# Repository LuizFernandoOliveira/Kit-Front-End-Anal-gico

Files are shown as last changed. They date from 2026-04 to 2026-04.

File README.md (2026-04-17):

# Kit Front-End Analógico




## Descrição
Kit didático completo de Front-End para circuitos analógicos. Este kit é perfeito para se ter na bancada, pois possui diversas funcionalidades úteis durante o desenvolvimente de sistemas microcontrolados e IoT.

<p align="center">
  kitFrontEndAnalogico
</p>

---

## Descrições técnicas

- Possui LDOs de 3V3 e 5V;
- Conectores USB tipo-C e Jack para alimentação do circuito;
- Possui AmpOp Full Diferencial;
- Possui ADC Full Diferencial:
- Possui Filtro ativo de 2ª Oedem Passa-altas, Passa-baixas, Passa-faixas, Rejeita-faixas;
- Possui Filtros passivos;
- Possui Buffer;
- Possui AmpOp de instrumentação;
- Possui divisores de tensão;
- Possui resistores de Pull-Up e/ou Pull-Down;
- Possui AmpOp RRIO, Ultra-Low Power, Ultra-Low Noise Não Inversor, Inversor, Integrador, Diferenciador;
- Possui chaves analogicas;
- Possui chaves digitais;
- Possui botões e LEDS;
- Possui sensores analógicos;
- Possui diodos Schotky;
- Possui diversas tensões de referência;
- Possui diversos charge pumps.

---

## Estrutura do repositório
Os arquivos de hardware foram desenvolvidos utilizando o KiCad 9.0.
- **`.kicad_pcb`**: Layout da placa de circuito impresso (Board).
- **`.kicad_sch`**: Esquemático eletrônico do sistema (Schematic).
- **`.kicad_pro`**: Gerenciador de projeto do KiCad (Project).

---

## Autor
**Dr. Luiz Fernando Pinto de Oliveira**

*Engenheiro Eletrônico especializado em Sistemas Embarcados e Ultra-Low Power.*
- **Website:** [FAPLO](https://faplo.webnode.page/)
- **LinkedIn:** [lfpo](https://www.linkedin.com/in/lfpo/)

---

Shield: [][cc-by-nc-nd]

This work is licensed under a
[Creative Commons Attribution-NonCommercial-NoDerivs 4.0 International License][cc-by-nc-nd].

[][cc-by-nc-nd]

[cc-by-nc-nd]: http://creativecommons.org/licenses/by-nc-nd/4.0/
[cc-by-nc-nd-image]: https://licensebuttons.net/l/by-nc-nd/4.0/88x31.png
[cc-by-nc-nd-shield]: https://img.shields.io/badge/License-CC%20BY--NC--ND%204.0-lightgrey.svg

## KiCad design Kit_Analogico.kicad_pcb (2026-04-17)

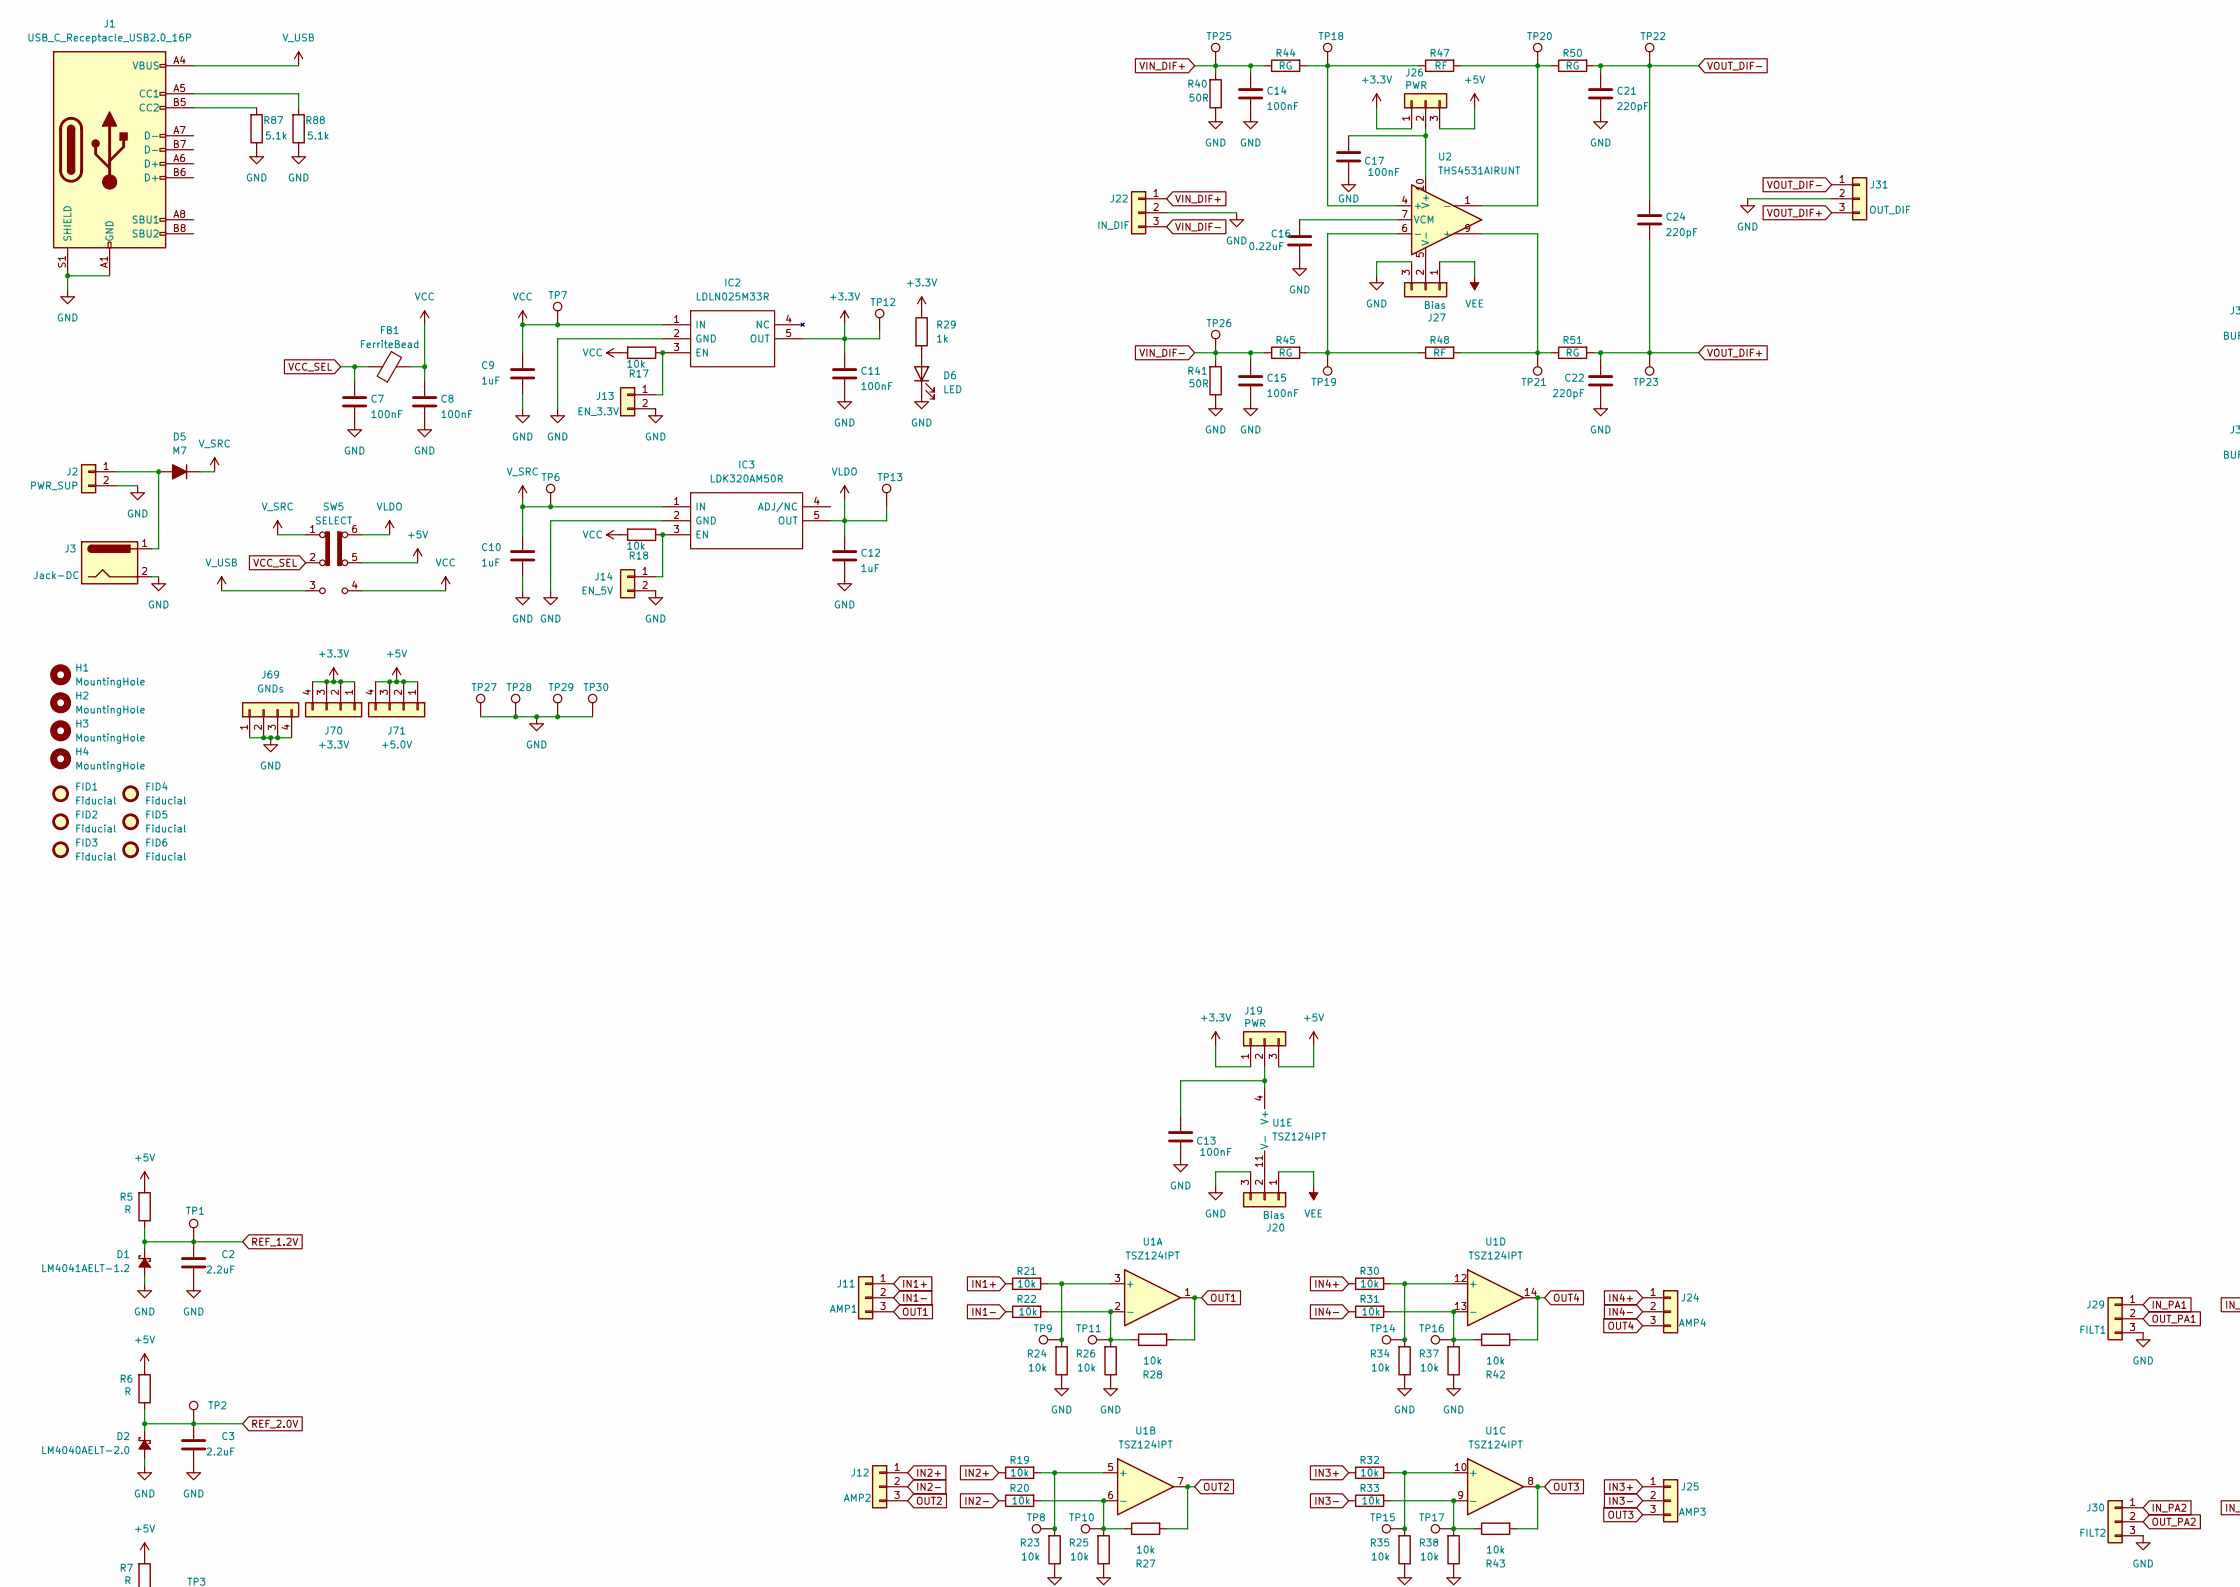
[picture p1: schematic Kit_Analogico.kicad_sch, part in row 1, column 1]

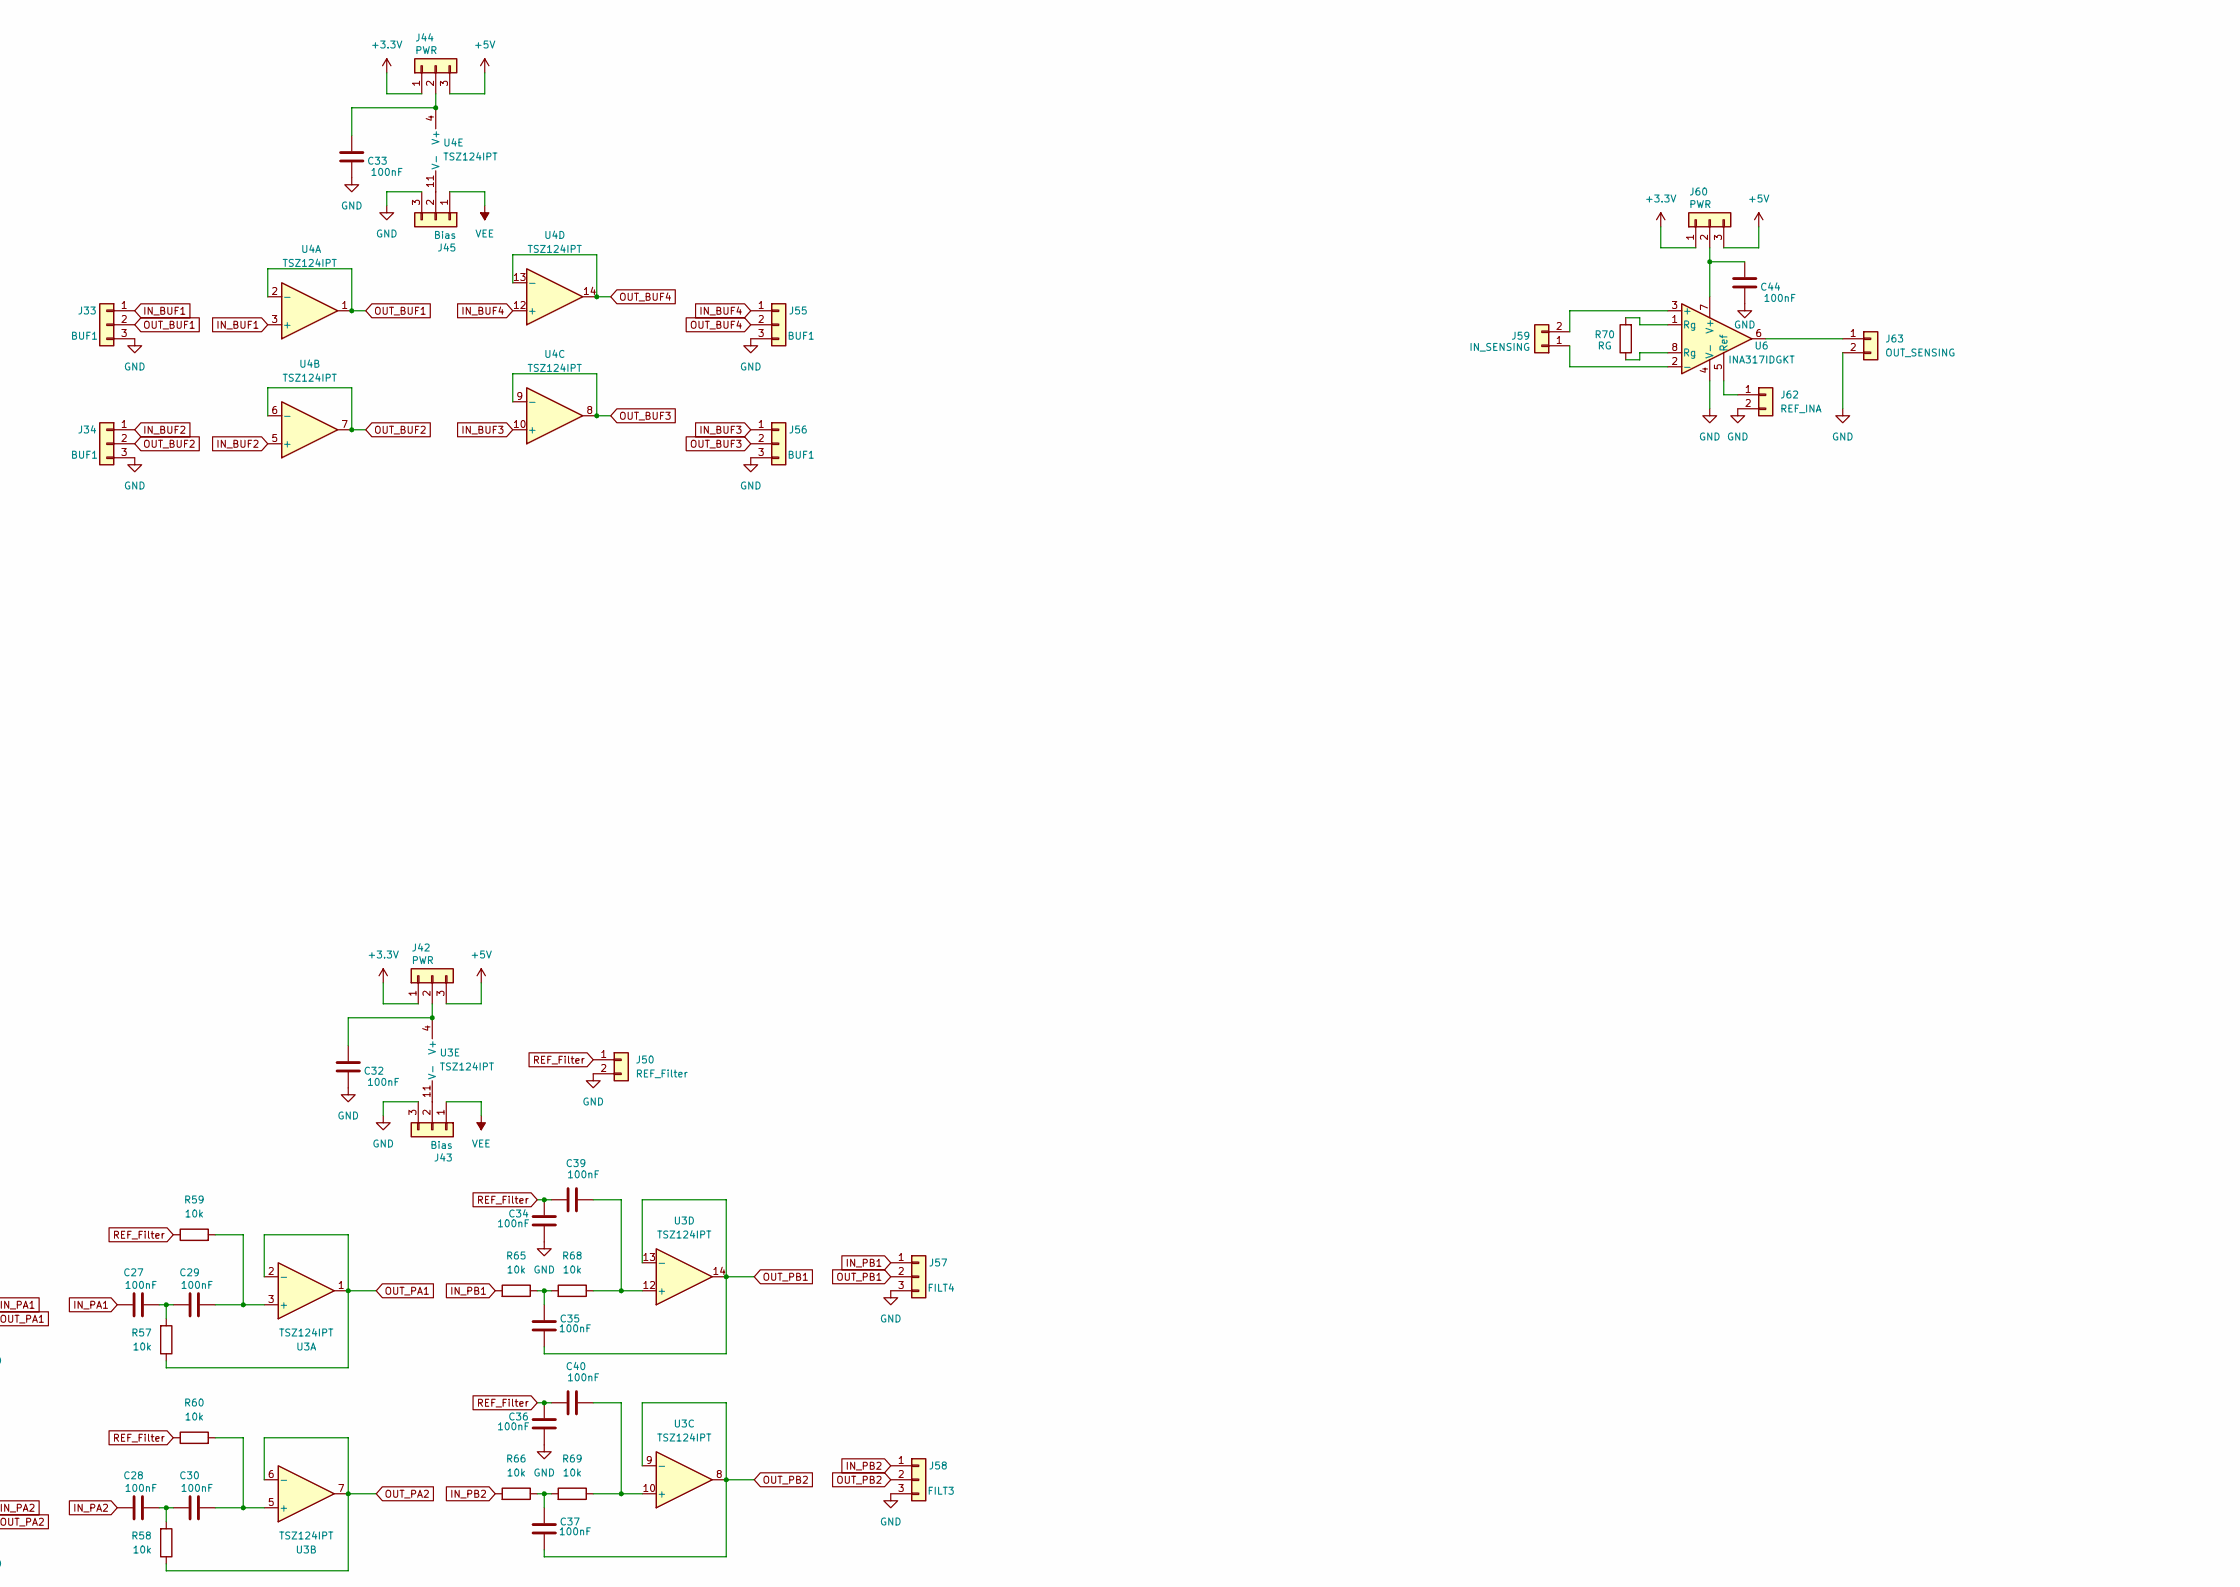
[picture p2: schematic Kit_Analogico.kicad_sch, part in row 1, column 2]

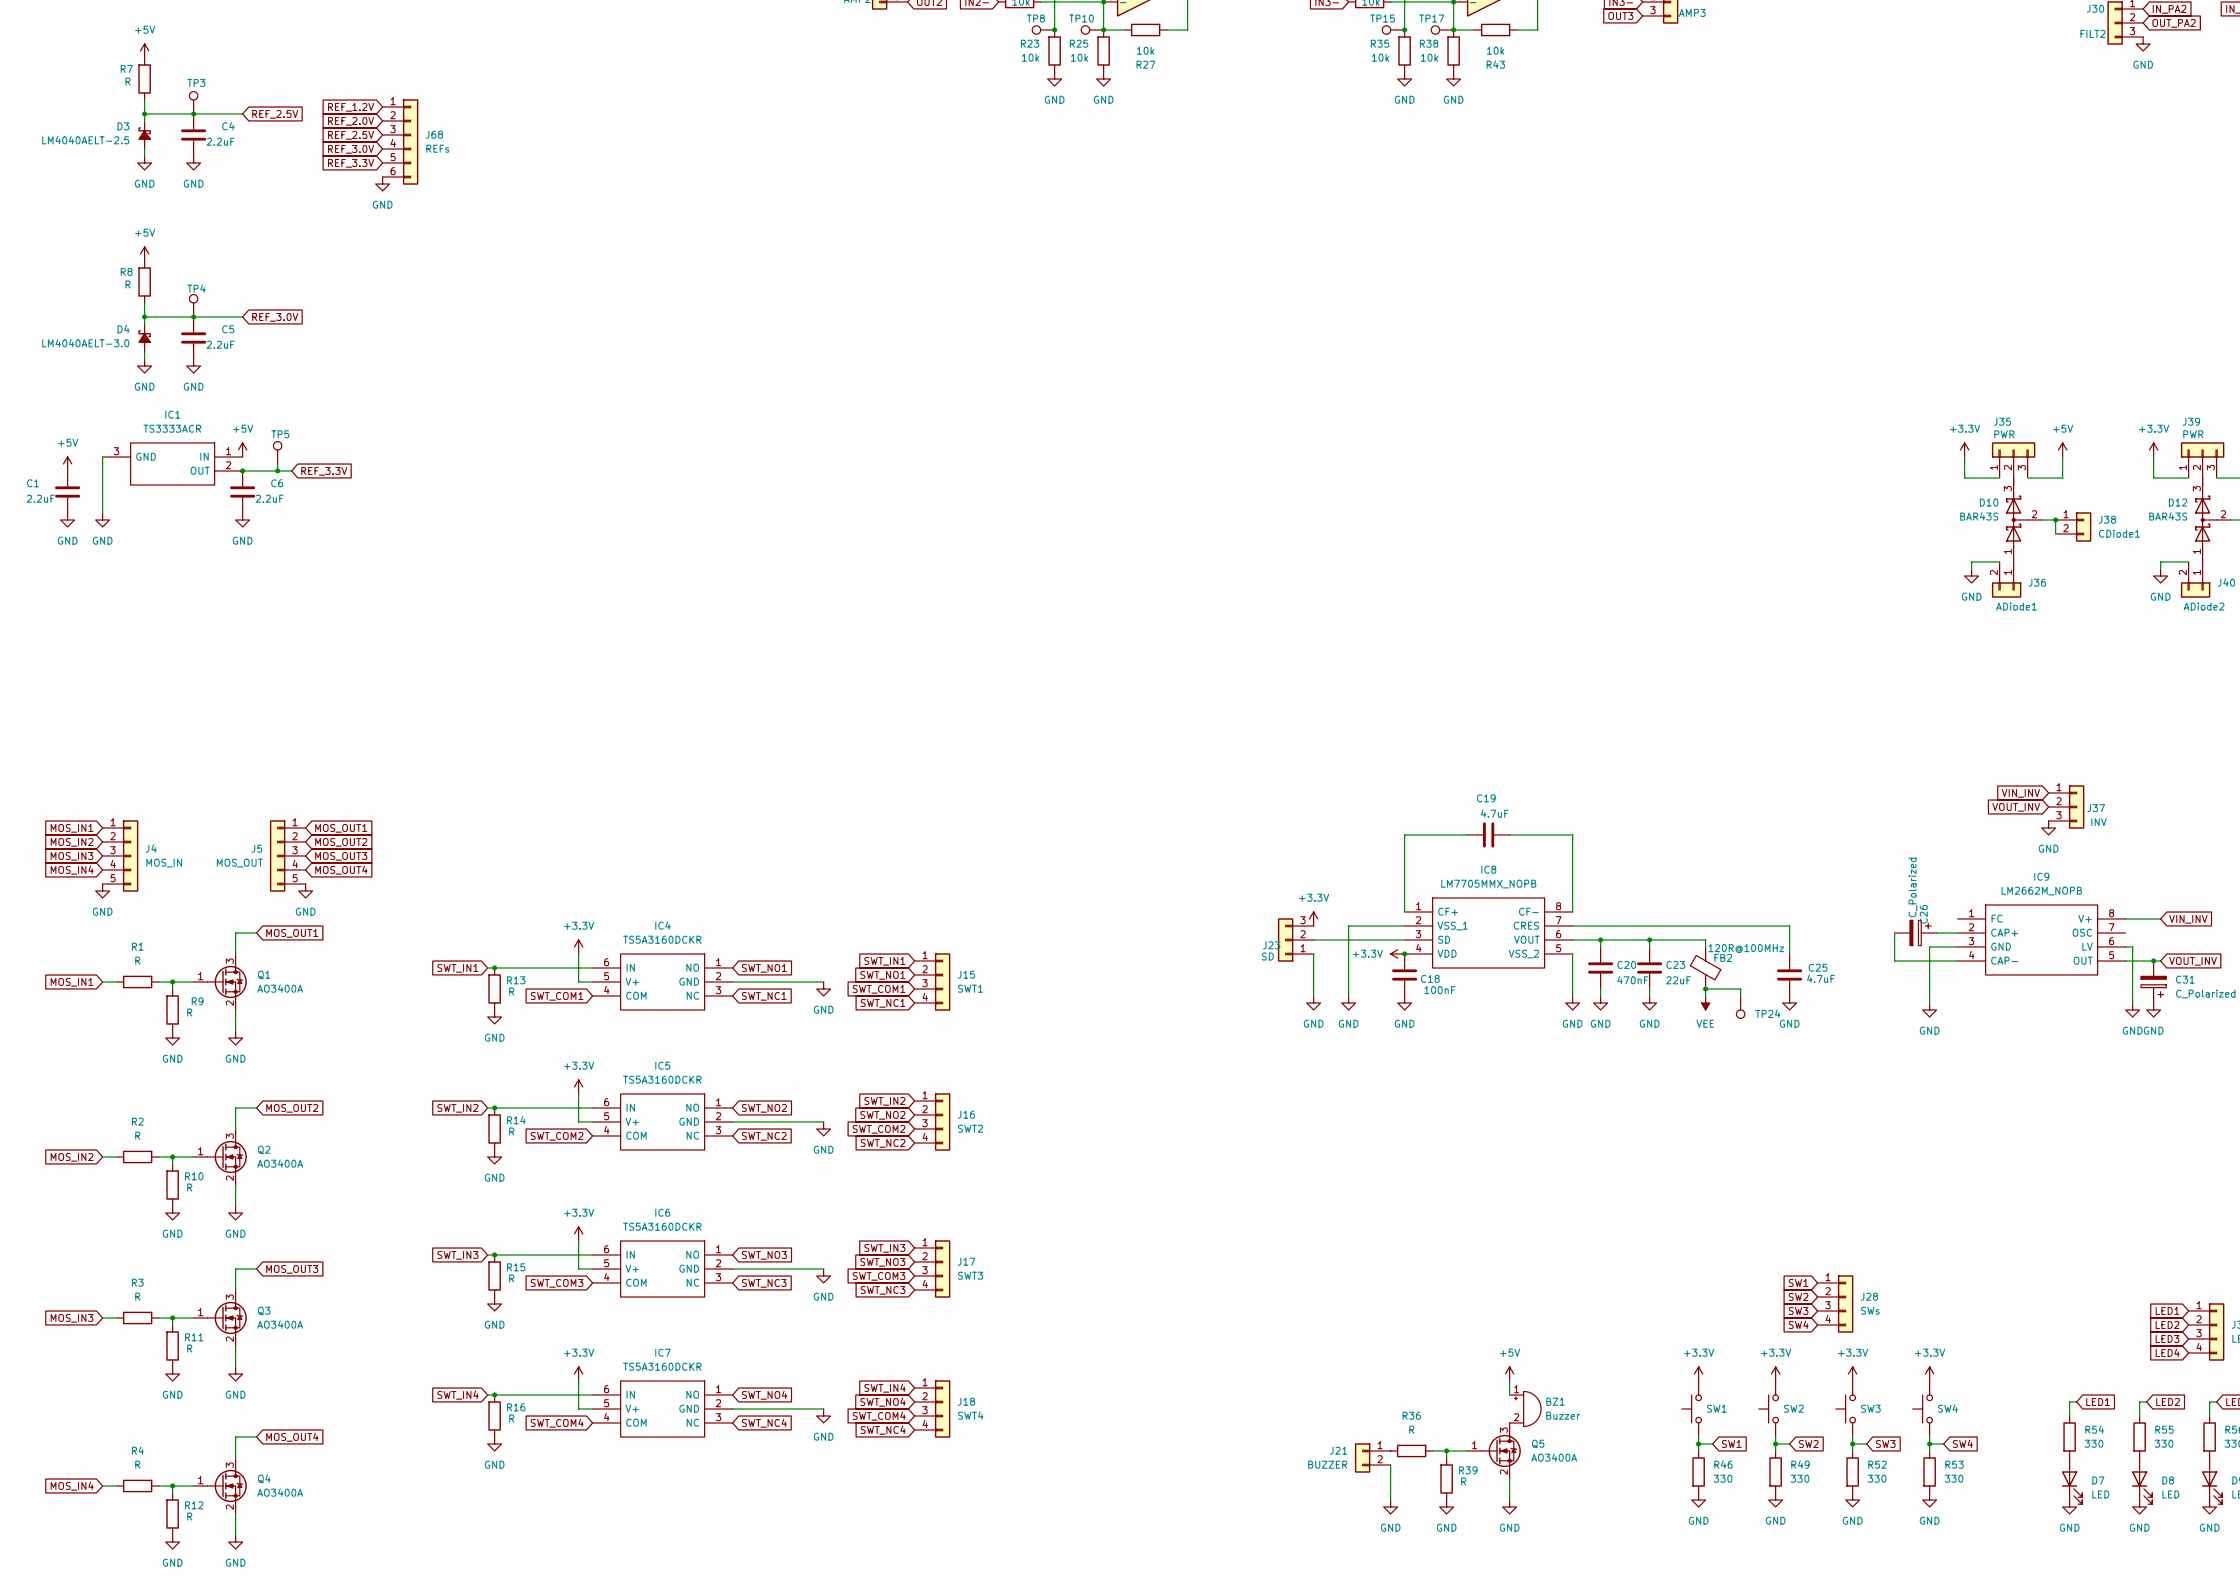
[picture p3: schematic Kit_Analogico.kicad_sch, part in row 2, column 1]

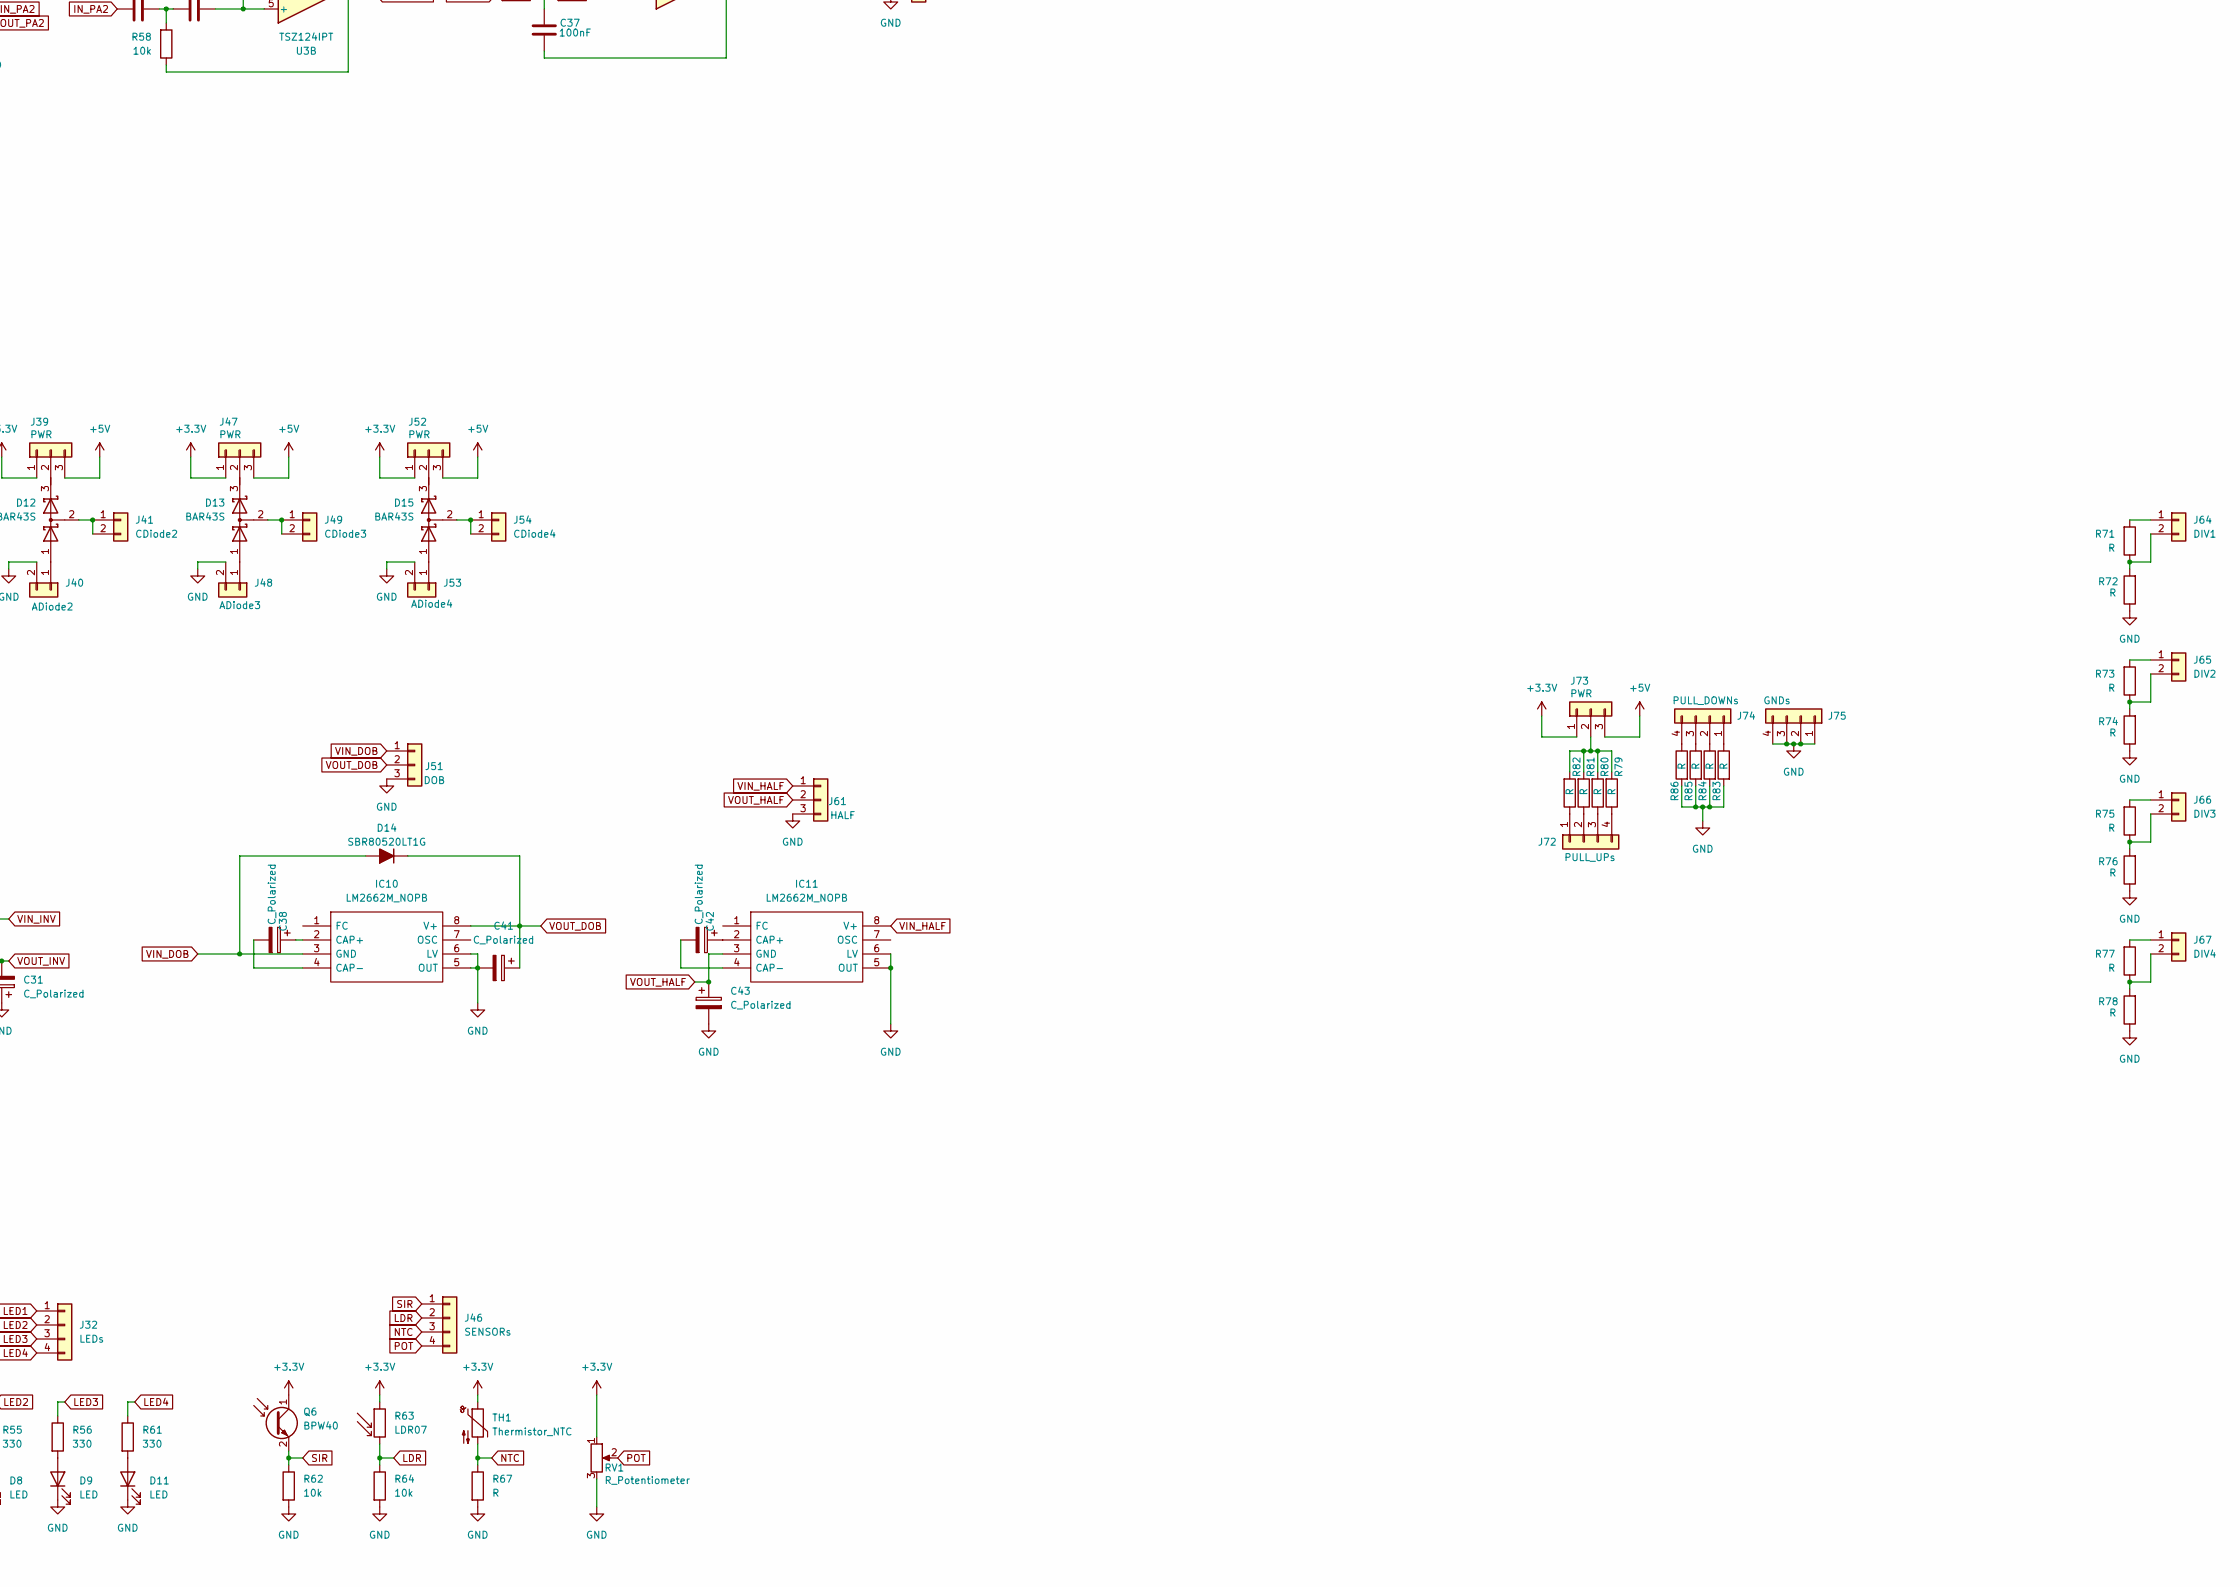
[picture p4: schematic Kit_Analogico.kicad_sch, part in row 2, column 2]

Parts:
BZ1: Buzzer; Buzzer_12x9.5RM7.6
C1, C2, C3, C4, C5, C6: 2.2uF; C_0805_2012Metric
C7, C8, C11, C13, C14, C15, C17, C18, C27, C28, C29, C30, C32, C33, C34, C35, C36, C37, C39, C40, C44: 100nF; C_0805_2012Metric
C9, C10, C12: 1uF; C_0805_2012Metric
C16: 0.22uF; C_0805_2012Metric
C19, C25: 4.7uF; C_0805_2012Metric
C20: 470nF; C_0805_2012Metric
C21, C22, C24: 220pF; C_0805_2012Metric
C23: 22uF; C_0805_2012Metric
C26, C31, C38, C41, C42, C43: C_Polarized; CP_EIA-3216-10_Kemet-I_Pad1.58x1.35mm_HandSolder
D1: LM4041AELT-1.2; LM4040AELT25
D2: LM4040AELT-2.0; LM4040AELT25
D3: LM4040AELT-2.5; LM4040AELT25
D4: LM4040AELT-3.0; LM4040AELT25
D5: M7; D_SMA
D6, D7, D8, D9, D11: LED; LED_0805_2012Metric
D10, D12, D13, D15: BAR43S; SOT95P237X112-3N
D14: SBR80520LT1G; SOD3716X135N
FB1: FerriteBead; L_0805_2012Metric
FB2: 120R@100MHz; L_0805_2012Metric
FID1, FID2, FID3, FID4, FID5, FID6: Fiducial; Fiducial_1mm_Mask2mm
H1, H2, H3, H4: MountingHole; MountingHole_3.2mm_M3_DIN965
IC1: TS3333ACR; LM4040CELT20; Manufacturer_Part_Number TS3333ACR
IC2: LDLN025M33R; SOT95P280X145-5N; Manufacturer_Part_Number LDLN025M33R; Mouser Part Number 511-LDLN025M33R
IC3: LDK320AM50R; SOT95P280X145-5N; Manufacturer_Part_Number LDK320AM50R; Mouser Part Number 511-LDK320AM50R
IC4, IC5, IC6, IC7: TS5A3160DCKR; SOT65P210X110-6N; Manufacturer_Part_Number TS5A3160DCKR; Mouser Part Number 595-TS5A3160DCKR
IC8: LM7705MMX_NOPB; SOP65P490X110-8N; Manufacturer_Part_Number LM7705MMX/NOPB; Mouser Part Number 926-LM7705MMX/NOPB
IC9, IC10, IC11: LM2662M_NOPB; SOIC127P600X175-8N; Manufacturer_Part_Number LM2662M/NOPB; Mouser Part Number 926-LM2662M/NOPB
J1: USB_C_Receptacle_USB2.0_16P; USB_C_Receptacle_HRO_TYPE-C-31-M-12
J2: PWR_SUP; TerminalBlock_Altech_AK300-2_P5.00mm
J3: Jack-DC; BarrelJack_Horizontal
J4: MOS_IN; PinHeader_1x05_P2.54mm_Vertical
J5: MOS_OUT; PinHeader_1x05_P2.54mm_Vertical
J11: AMP1; PinHeader_1x03_P2.54mm_Vertical
J12: AMP2; PinHeader_1x03_P2.54mm_Vertical
J13: EN_3.3V; PinHeader_1x02_P2.54mm_Vertical
J14: EN_5V; PinHeader_1x02_P2.54mm_Vertical
J15: SWT1; PinHeader_1x04_P2.54mm_Vertical
J16: SWT2; PinHeader_1x04_P2.54mm_Vertical
J17: SWT3; PinHeader_1x04_P2.54mm_Vertical
J18: SWT4; PinHeader_1x04_P2.54mm_Vertical
J19, J26, J35, J39, J42, J44, J47, J52, J60, J73: PWR; PinHeader_1x03_P2.54mm_Vertical
J20, J27, J43, J45: Bias; PinHeader_1x03_P2.54mm_Vertical
J21: BUZZER; PinHeader_1x02_P2.54mm_Vertical
J22: IN_DIF; PinHeader_1x03_P2.54mm_Vertical
J23: SD; PinHeader_1x03_P2.54mm_Vertical
J24: AMP4; PinHeader_1x03_P2.54mm_Vertical
J25: AMP3; PinHeader_1x03_P2.54mm_Vertical
J28: SWs; PinHeader_1x04_P2.54mm_Vertical
J29: FILT1; PinHeader_1x03_P2.54mm_Vertical
J30: FILT2; PinHeader_1x03_P2.54mm_Vertical
J31: OUT_DIF; PinHeader_1x03_P2.54mm_Vertical
J32: LEDs; PinHeader_1x04_P2.54mm_Vertical
J33, J34, J55, J56: BUF1; PinHeader_1x03_P2.54mm_Vertical
J36: ADiode1; PinHeader_1x02_P2.54mm_Vertical
J37: INV; PinHeader_1x03_P2.54mm_Vertical
J38: CDiode1; PinHeader_1x02_P2.54mm_Vertical
J40: ADiode2; PinHeader_1x02_P2.54mm_Vertical
J41: CDiode2; PinHeader_1x02_P2.54mm_Vertical
J46: SENSORs; PinHeader_1x04_P2.54mm_Vertical
J48: ADiode3; PinHeader_1x02_P2.54mm_Vertical
J49: CDiode3; PinHeader_1x02_P2.54mm_Vertical
J50: REF_Filter; PinHeader_1x02_P2.54mm_Vertical
J51: DOB; PinHeader_1x03_P2.54mm_Vertical
J53: ADiode4; PinHeader_1x02_P2.54mm_Vertical
J54: CDiode4; PinHeader_1x02_P2.54mm_Vertical
J57: FILT4; PinHeader_1x03_P2.54mm_Vertical
J58: FILT3; PinHeader_1x03_P2.54mm_Vertical
J59: IN_SENSING; PinHeader_1x02_P2.54mm_Vertical
J61: HALF; PinHeader_1x03_P2.54mm_Vertical
J62: REF_INA; PinHeader_1x02_P2.54mm_Vertical
J63: OUT_SENSING; PinHeader_1x02_P2.54mm_Vertical
J64: DIV1; PinHeader_1x02_P2.54mm_Vertical
J65: DIV2; PinHeader_1x02_P2.54mm_Vertical
J66: DIV3; PinHeader_1x02_P2.54mm_Vertical
J67: DIV4; PinHeader_1x02_P2.54mm_Vertical
J68: REFs; PinHeader_1x06_P2.54mm_Vertical
J69, J75: GNDs; PinHeader_1x04_P2.54mm_Vertical
J70: +3.3V; PinHeader_1x04_P2.54mm_Vertical
J71: +5.0V; PinHeader_1x04_P2.54mm_Vertical
J72: PULL_UPs; PinHeader_1x04_P2.54mm_Vertical
J74: PULL_DOWNs; PinHeader_1x04_P2.54mm_Vertical
Q1, Q2, Q3, Q4, Q5: AO3400A; SOT-23
Q6: BPW40; LED_D5.0mm_Clear
R1, R2, R3, R4, R5, R6, R7, R8, R9, R10, R11, R12, R13, R14, R15, R16, R36, R39, R67, R71, R72, R73, R74, R75, R76, R77, R78, R79, R80, R81, R82, R83, R84, R85, R86: R; R_0805_2012Metric
R17, R18, R19, R20, R21, R22, R23, R24, R25, R26, R27, R28, R30, R31, R32, R33, R34, R35, R37, R38, R42, R43, R57, R58, R59, R60, R62, R64, R65, R66, R68, R69: 10k; R_0805_2012Metric
R29: 1k; R_0805_2012Metric
R40, R41: 50R; R_0805_2012Metric
R44, R45, R50, R51, R70: RG; R_0805_2012Metric
R46, R49, R52, R53, R54, R55, R56, R61: 330; R_0805_2012Metric
R47, R48: RF; R_0805_2012Metric
R63: LDR07; R_LDR_5.1x4.3mm_P3.4mm_Vertical
R87, R88: 5.1k; R_0805_2012Metric
RV1: R_Potentiometer; RM065503
SW1, SW2, SW3, SW4: SW_Push; SW_PUSH_6mm_H5mm
SW5: SELECT; SW_E-Switch_EG1271_SPDT
TH1: Thermistor_NTC; PinHeader_1x02_P2.54mm_Vertical
TP1, TP2, TP3, TP4, TP5, TP6, TP7, TP8, TP9, TP10, TP11, TP12, TP13, TP14, TP15, TP16, TP17, TP18, TP19, TP20, TP21, TP22, TP23, TP24, TP25, TP26, TP27, TP28, TP29, TP30: TestPoint; TestPoint_Loop_D1.80mm_Drill1.0mm_Beaded
U1, U3, U4: TSZ124IPT; SOP65P640X120-14N
U2: THS4531AIRUNT; QFN50P200X200X80-10N-D
U6: INA317IDGKT; SOP65P490X110-8N

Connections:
+3.3V: C11.1, C18.2, IC2.5 (OUT), IC4.5 (V+), IC5.5 (V+), IC6.5 (V+), IC7.5 (V+), IC8.4 (VDD), J19.1, J23.3, J26.1, J35.1, J39.1, J42.1, J44.1, J47.1, J52.1, J60.1, J70.1, J70.2, J70.3, J70.4, J73.1, Q6.1 (C), R29.1, R63.1, RV1.1, SW1.2, SW2.2, SW3.2, SW4.2, TH1.1, TP12.1
+5V: BZ1.1 (+), C1.1, IC1.1 (IN), J19.3, J26.3, J35.3, J39.3, J42.3, J44.3, J47.3, J52.3, J60.3, J71.1, J71.2, J71.3, J71.4, J73.3, R5.2, R6.2, R7.2, R8.2, SW5.5 (B)
GND: C1.2, C2.2, C3.2, C4.2, C5.2, C6.2, C7.2, C8.2, C9.2, C10.2, C11.2, C12.2, C13.1, C14.2, C15.2, C16.2, C17.1, C18.1, C20.2, C21.2, C22.2, C23.2, C25.1, C31.1, C32.1, C33.1, C34.1, C36.1, C41.2, C43.2, C44.1, D1.2 (A), D2.2 (A), D3.2 (A), D4.2 (A), D6.1 (K), D7.1 (K), D8.1 (K), D9.1 (K), D11.1 (K), IC1.3 (GND), IC2.2 (GND), IC3.2 (GND), IC4.2 (GND), IC5.2 (GND), IC6.2 (GND), IC7.2 (GND), IC8.2 (VSS_1), IC8.5 (VSS_2), IC9.3 (GND), IC9.6 (LV), IC10.5 (OUT), IC10.6 (LV), IC11.5 (OUT), IC11.6 (LV), J1.A1 (GND), J1.A12 (GND), J1.B1 (GND), J1.B12 (GND), J1.S1 (SHIELD), J2.2, J3.2, J4.5, J5.5, J13.2, J14.2, J20.3, J21.2, J22.2, J23.1, J27.3, J29.3, J30.3, J31.2, J33.3, J34.3, J36.2, J37.3, J40.2, J43.3, J45.3, J48.2, J50.2, J51.3, J53.2, J55.3, J56.3, J57.3, J58.3, J61.3, J62.2, J63.2, J68.6, J69.1, J69.2, J69.3, J69.4, J75.1, J75.2, J75.3, J75.4, Q1.2 (S), Q2.2 (S), Q3.2 (S), Q4.2 (S), Q5.2 (S), R9.1, R10.1, R11.1, R12.1, R13.1, R14.1, R15.1, R16.1, R23.1, R24.1, R25.1, R26.1, R34.1, R35.1, R37.1, R38.1, R39.1, R40.1, R41.1, R46.2, R49.2, R52.2, R53.2, R62.2, R64.2, R67.2, R72.1, R74.1, R76.1, R78.1, R83.2, R84.2, R85.2, R86.2, R87.1, R88.1, RV1.3, TP27.1, TP28.1, TP29.1, TP30.1, U6.4 (V-)
IN1+: J11.1, R21.1
IN1-: J11.2, R22.1
IN2+: J12.1, R19.1
IN2-: J12.2, R20.1
IN3+: J25.1, R32.1
IN3-: J25.2, R33.1
IN4+: J24.1, R30.1
IN4-: J24.2, R31.1
IN_BUF1: J33.1, U4.3 (+)
IN_BUF2: J34.1, U4.5 (+)
IN_BUF3: J56.1, U4.10 (+)
IN_BUF4: J55.1, U4.12 (+)
IN_PA1: C27.2, J29.1
IN_PA2: C28.2, J30.1
IN_PB1: J57.1, R65.2
IN_PB2: J58.1, R66.2
LDR: J46.2, R63.2, R64.1
LED1: J32.1, R54.1
LED2: J32.2, R55.1
LED3: J32.3, R56.1
LED4: J32.4, R61.1
MOS_IN1: J4.1, R1.1
MOS_IN2: J4.2, R2.1
MOS_IN3: J4.3, R3.1
MOS_IN4: J4.4, R4.1
MOS_OUT1: J5.1, Q1.3 (D)
MOS_OUT2: J5.2, Q2.3 (D)
MOS_OUT3: J5.3, Q3.3 (D)
MOS_OUT4: J5.4, Q4.3 (D)
NTC: J46.3, R67.1, TH1.2
unnamed: BZ1.2 (-), Q5.3 (D)
unnamed: C27.1, C29.2, R57.2
unnamed: C28.1, C30.2, R58.2
unnamed: C35.2, R65.1, R68.2
unnamed: C37.2, R66.1, R69.2
unnamed: D5.2 (A), J2.1, J3.1
unnamed: D6.2 (A), R29.2
unnamed: D7.2 (A), R54.2
unnamed: D8.2 (A), R55.2
unnamed: D9.2 (A), R56.2
unnamed: D10.1 (A), J36.1
unnamed: D10.3 (K), J35.2
unnamed: D10.2 (common), J38.1, J38.2
unnamed: D11.2 (A), R61.2
unnamed: D12.1 (A), J40.1
unnamed: D12.3 (K), J39.2
unnamed: D12.2 (common), J41.1, J41.2
unnamed: D13.1 (A), J48.1
unnamed: D13.3 (K), J47.2
unnamed: D13.2 (common), J49.1, J49.2
unnamed: D15.1 (A), J53.1
unnamed: D15.3 (K), J52.2
unnamed: D15.2 (common), J54.1, J54.2
unnamed: IC2.3 (EN), J13.1, R17.1
unnamed: IC3.3 (EN), J14.1, R18.1
unnamed: C19.1, IC8.1 (CF+)
unnamed: C19.2, IC8.8 (CF-)
unnamed: C25.2, IC8.7 (CRES)
unnamed: IC8.3 (SD), J23.2
unnamed: C20.1, C23.1, FB2.1, IC8.6 (VOUT)
unnamed: C26.1, IC9.2 (CAP+)
unnamed: C26.2, IC9.4 (CAP-)
unnamed: C38.1, IC10.2 (CAP+)
unnamed: C38.2, IC10.4 (CAP-)
unnamed: C42.1, IC11.2 (CAP+)
unnamed: C42.2, IC11.4 (CAP-)
unnamed: J1.A5 (CC1), R88.2
unnamed: J1.B5 (CC2), R87.2
unnamed: C13.2, J19.2, U1.4 (V+)
unnamed: J20.2, U1.11 (V-)
unnamed: J21.1, R36.1
unnamed: C17.2, J26.2, U2.10 (V+)
unnamed: J27.2, U2.5 (V-)
unnamed: C32.2, J42.2, U3.4 (V+)
unnamed: J43.2, U3.11 (V-)
unnamed: C33.2, J44.2, U4.4 (V+)
unnamed: J45.2, U4.11 (V-)
unnamed: J59.1, U6.2 (-)
unnamed: J59.2, U6.3 (+)
unnamed: C44.2, J60.2, U6.7 (V+)
unnamed: J62.1, U6.5 (Ref)
unnamed: J63.1, U6.6
unnamed: J64.1, R71.2
unnamed: J64.2, R71.1, R72.2
unnamed: J65.1, R73.2
unnamed: J65.2, R73.1, R74.2
unnamed: J66.1, R75.2
unnamed: J66.2, R75.1, R76.2
unnamed: J67.1, R77.2
unnamed: J67.2, R77.1, R78.2
unnamed: J72.1, R82.1
unnamed: J72.2, R81.1
unnamed: J72.3, R80.1
unnamed: J72.4, R79.1
unnamed: J73.2, R79.2, R80.2, R81.2, R82.2
unnamed: J74.1, R83.1
unnamed: J74.2, R84.1
unnamed: J74.3, R85.1
unnamed: J74.4, R86.1
unnamed: Q1.1 (G), R1.2, R9.2
unnamed: Q2.1 (G), R2.2, R10.2
unnamed: Q3.1 (G), R3.2, R11.2
unnamed: Q4.1 (G), R4.2, R12.2
unnamed: Q5.1 (G), R36.2, R39.2
unnamed: R44.2, R47.1, TP18.1, U2.4 (+)
unnamed: R45.2, R48.1, TP19.1, U2.6 (-)
unnamed: R47.2, R50.1, TP20.1, U2.1 (-)
unnamed: R48.2, R51.1, TP21.1, U2.9 (+)
unnamed: R70.1, U6.8 (Rg)
unnamed: R70.2, U6.1 (Rg)
unnamed: R21.2, R24.2, TP9.1, U1.3 (+)
unnamed: R22.2, R26.2, R28.1, TP11.1, U1.2 (-)
unnamed: R19.2, R23.2, TP8.1, U1.5 (+)
unnamed: R20.2, R25.2, R27.1, TP10.1, U1.6 (-)
unnamed: R32.2, R35.2, TP15.1, U1.10 (+)
unnamed: R33.2, R38.2, R43.1, TP17.1, U1.9 (-)
unnamed: R30.2, R34.2, TP14.1, U1.12 (+)
unnamed: R31.2, R37.2, R42.1, TP16.1, U1.13 (-)
unnamed: C16.1, U2.7 (VCM)
unnamed: C29.1, R59.2, U3.3 (+)
unnamed: C30.1, R60.2, U3.5 (+)
unnamed: C40.1, R69.1, U3.10 (+)
unnamed: C39.1, R68.1, U3.12 (+)
OUT1: J11.3, R28.2, U1.1
OUT2: J12.3, R27.2, U1.7
OUT3: J25.3, R43.2, U1.8
OUT4: J24.3, R42.2, U1.14
OUT_BUF1: J33.2, U4.1, U4.2 (-)
OUT_BUF2: J34.2, U4.6 (-), U4.7
OUT_BUF3: J56.2, U4.8, U4.9 (-)
OUT_BUF4: J55.2, U4.13 (-), U4.14
OUT_PA1: J29.2, R57.1, U3.1, U3.2 (-)
OUT_PA2: J30.2, R58.1, U3.6 (-), U3.7
OUT_PB1: C35.1, J57.2, U3.13 (-), U3.14
OUT_PB2: C37.1, J58.2, U3.8, U3.9 (-)
POT: J46.4, RV1.2
REF_1.2V: C2.1, D1.1 (K), J68.1, R5.1, TP1.1
REF_2.0V: C3.1, D2.1 (K), J68.2, R6.1, TP2.1
REF_2.5V: C4.1, D3.1 (K), J68.3, R7.1, TP3.1
REF_3.0V: C5.1, D4.1 (K), J68.4, R8.1, TP4.1
REF_3.3V: C6.1, IC1.2 (OUT), J68.5, TP5.1
REF_Filter: C34.2, C36.2, C39.2, C40.2, J50.1, R59.1, R60.1
SIR: J46.1, Q6.2 (E), R62.1
SW1: J28.1, R46.1, SW1.1
SW2: J28.2, R49.1, SW2.1
SW3: J28.3, R52.1, SW3.1
SW4: J28.4, R53.1, SW4.1
SWT_COM1: IC4.4 (COM), J15.3
SWT_COM2: IC5.4 (COM), J16.3
SWT_COM3: IC6.4 (COM), J17.3
SWT_COM4: IC7.4 (COM), J18.3
SWT_IN1: IC4.6 (IN), J15.1, R13.2
SWT_IN2: IC5.6 (IN), J16.1, R14.2
SWT_IN3: IC6.6 (IN), J17.1, R15.2
SWT_IN4: IC7.6 (IN), J18.1, R16.2
SWT_NC1: IC4.3 (NC), J15.4
SWT_NC2: IC5.3 (NC), J16.4
SWT_NC3: IC6.3 (NC), J17.4
SWT_NC4: IC7.3 (NC), J18.4
SWT_NO1: IC4.1 (NO), J15.2
SWT_NO2: IC5.1 (NO), J16.2
SWT_NO3: IC6.1 (NO), J17.2
SWT_NO4: IC7.1 (NO), J18.2
VCC: C8.1, C9.1, FB1.2, IC2.1 (IN), R17.2, R18.2, SW5.4 (A), TP7.1
VCC_SEL: C7.1, FB1.1, SW5.2 (B)
VEE: FB2.2, J20.1, J27.1, J43.1, J45.1, TP24.1
VIN_DIF+: C14.1, J22.1, R40.2, R44.1, TP25.1
VIN_DIF-: C15.1, J22.3, R41.2, R45.1, TP26.1
VIN_DOB: D14.2 (A), IC10.3 (GND), J51.1
VIN_HALF: IC11.8 (V+), J61.1
VIN_INV: IC9.8 (V+), J37.1
VLDO: C12.1, IC3.5 (OUT), SW5.6 (C), TP13.1
VOUT_DIF+: C22.1, C24.2, J31.3, R51.2, TP23.1
VOUT_DIF-: C21.1, C24.1, J31.1, R50.2, TP22.1
VOUT_DOB: C41.1, D14.1 (K), IC10.8 (V+), J51.2
VOUT_HALF: C43.1, IC11.3 (GND), J61.2
VOUT_INV: C31.2, IC9.5 (OUT), J37.2
V_SRC: C10.1, D5.1 (K), IC3.1 (IN), SW5.1 (A), TP6.1
V_USB: J1.A4 (VBUS), J1.A9 (VBUS), J1.B4 (VBUS), J1.B9 (VBUS), SW5.3 (C)

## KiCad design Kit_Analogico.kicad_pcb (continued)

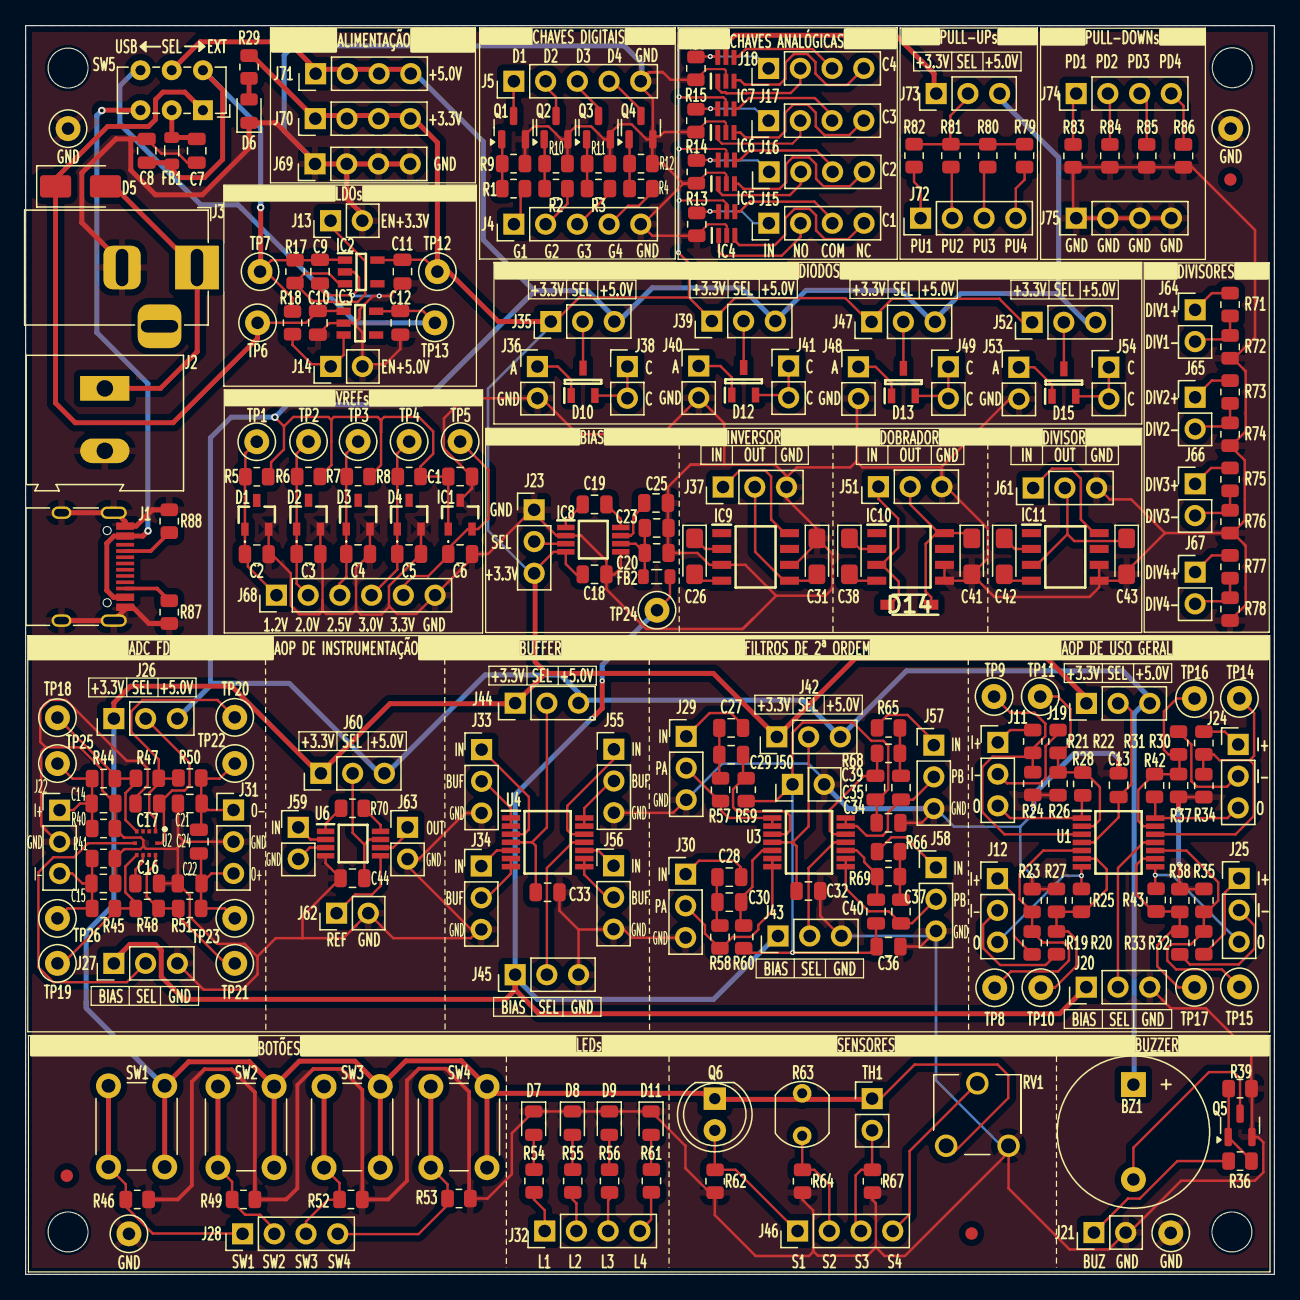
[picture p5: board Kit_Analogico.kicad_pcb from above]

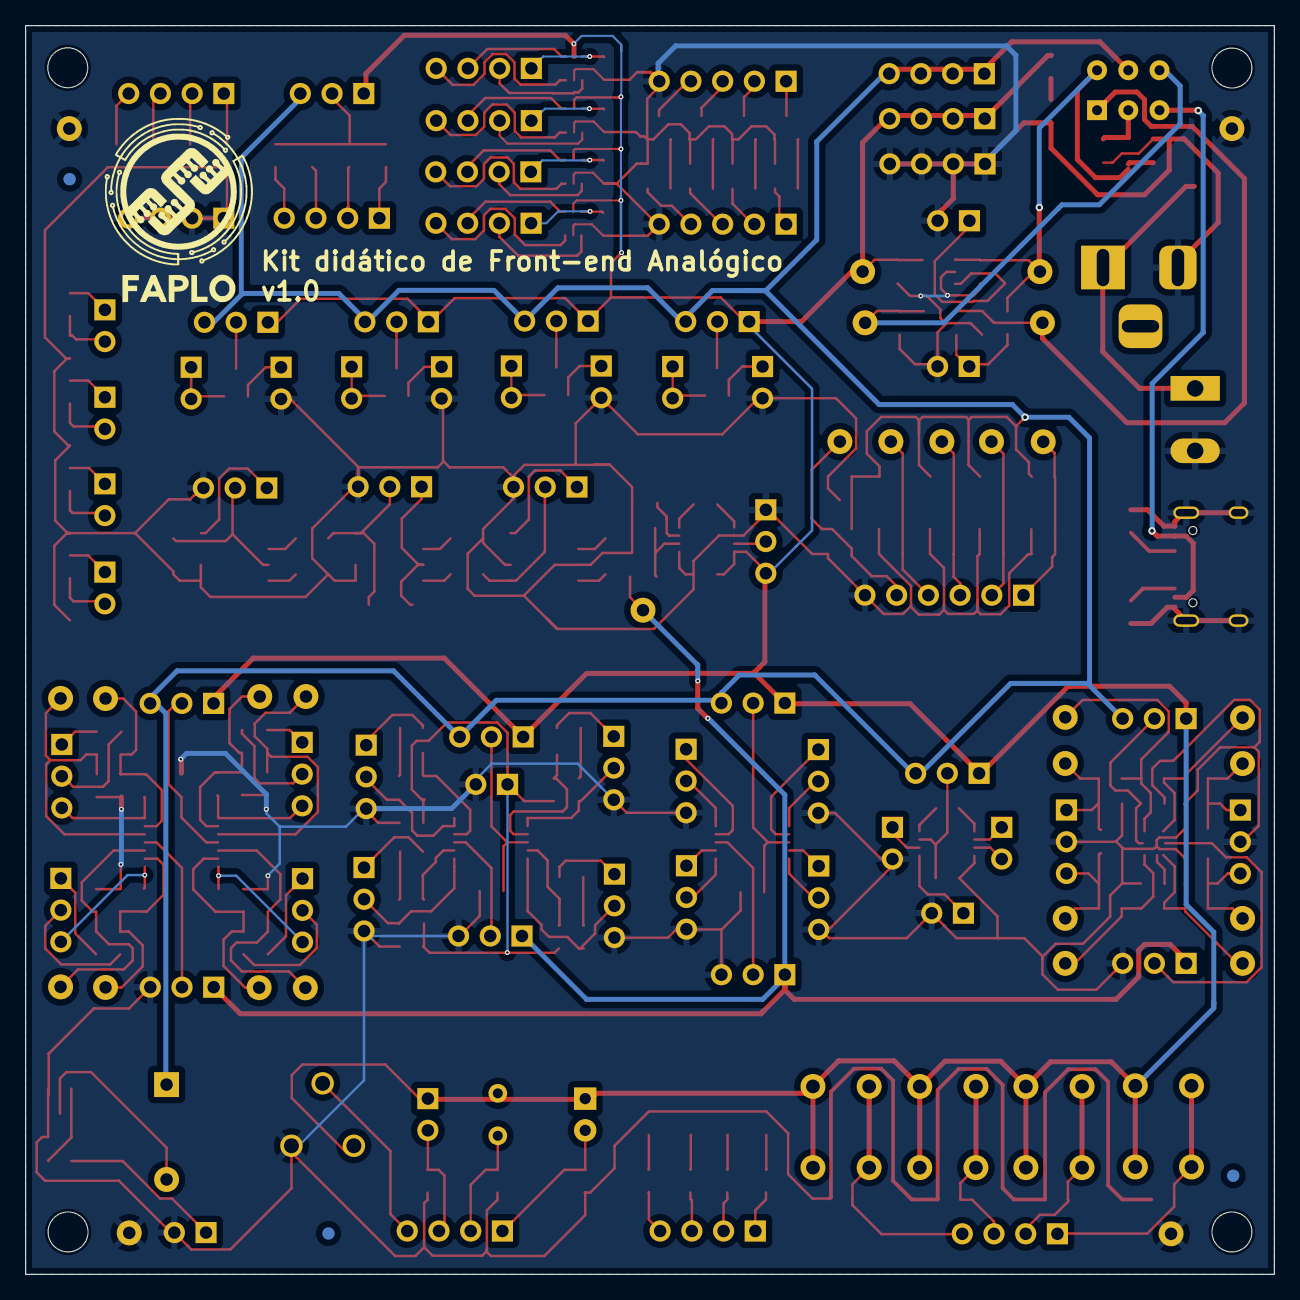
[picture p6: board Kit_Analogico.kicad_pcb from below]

Board: 2 copper layers, 100.0 x 100.0 mm, 289 parts (3 on the bottom side), 182 nets.

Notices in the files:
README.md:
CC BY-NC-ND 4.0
